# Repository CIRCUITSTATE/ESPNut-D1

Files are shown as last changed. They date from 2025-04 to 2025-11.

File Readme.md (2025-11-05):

# ESPNut-D1

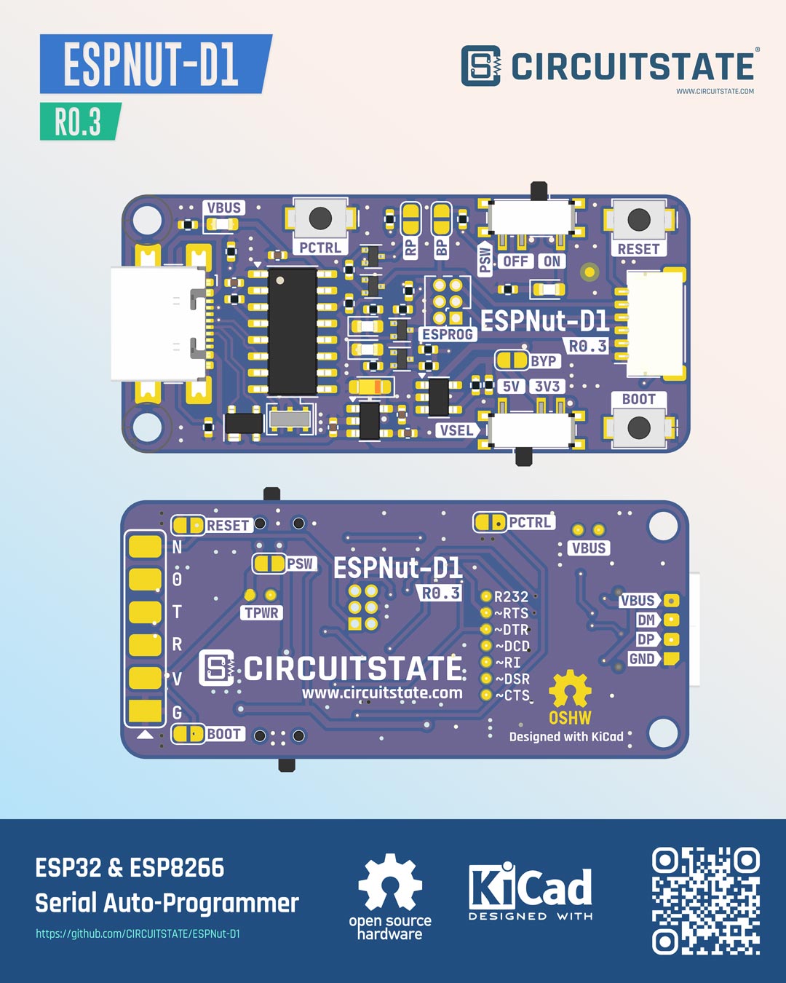
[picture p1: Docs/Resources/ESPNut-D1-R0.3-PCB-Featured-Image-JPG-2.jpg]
a title


[**ESPNut-D1**](https://github.com/CIRCUITSTATE/ESPNut-D1) (pronounced as **"ee yes peanut"**) is a single-channel USB-to-Serial converter and Auto-Programmer for the ESP32 & ESP8266 series microcontrollers from Espressif. While there exists many such programmers, ESPNut-D1 is a completely open-source hardware (OSHW) project designed in the **KiCad** open-source EDA tool. **D1** is the first design variant of this project. You can download the source files of this design, modify them and redistribute them as you wish.

ESPNut-D1 is based on the popular **CH340** series USB-to-Serial converter chip from *WCH*. The serial port of the chip connects to the target microcontroller through its own serial port. Thanks to the built-in serial bootloader of the ESP series microcontrollers, you can effortlessly program them at any time. The ESPNut-D1 makes this process a bit more convenient.

## Features

- CH340C/CH340G USB-to-Serial converter chip.
  - No external crystal required for the CH340C.
- USB-C connector with extra solderpads.
- Auto bootloader and reset circuit. Control both functions from the USB.
- Dedicated push-buttons for target reset and boot mode.
- 3.6~12V in, 3.3V out, 500 mA LDO.
- Slide switch for target power control.
- Target power control through load switch.
- SPDT slide switch for target voltage selection. Select between 3.3V and 5V.
- VBUS and target power indication LEDs.
- UART activity LEDs for both `TX` and `RX` lines.
- Dedicated push-button for power control of the target. Useful for boards without reset pin.
- 6-pin ESP-PROG 1.27 mm header.
- 6-pin JST-SH connector and solderpad for target ESP.
- 2x M2 mounting holes.

## Design

- **Parent Project:** ESPNut
- **Variant:** [ESPNut-D1](https://github.com/CIRCUITSTATE/ESPNut-D1)
- **Author:** Vishnu Mohanan (@vishnumaiea)
- **Latest Revision:** `R0.4`
- **Layer Count:** 2
- **Thickness:** 1.6 mm
- **Dimensions:** 44 x 20 mm
- **EDA Tool:** KiCad V9
- **License:** MIT

## Contributing

If you would like to contribute this project, you are welcome to post issues and feature requests on the **Issues** page. If you fork this project and created a new variant, you can let us know about it and get a unique identifier assigned for your project. The ID takes the following form.

```
Y<digit><letter><digit>
```

`Y` – Constant prefix.

`<digit>` – Digits from 0–9

`<letter>` – Characters from A–Z.

**Examples:**

```
Y1A1
Y1A2
Y2B1
Y3C4
```

The forked project should then be renamed to `ESPNut-D1-<ID>` form.

**Guidelines:**

- IDs are assigned upon request. You can create a new issue to request a new ID once a fork is created. Keep the issue title as `Request New ID` and include a link to your fork in the description.
- You can either request a new ID that you like and that is already not chosen, or allow us to choose an ID for you.
- You should rename the original source files with the `ESPNut-D1-<ID>` format.
- On the PCB, you can place the name of the project as `ESPNut-D1` and keep the ID as a standalone text on any visible layers.
- Once a unique ID is assigned to a forked project, the revision should be reset to `R0.1`. Do not keep the original revision of the project.

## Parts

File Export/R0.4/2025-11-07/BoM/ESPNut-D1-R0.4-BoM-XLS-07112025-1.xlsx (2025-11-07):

# | Reference | Value | Name | Footprint | Qty | DNP | MPN | MFR | Alt MPN
1 | C1,C8 | 47uF |  | Capacitor_SMD:C_0805_2012Metric | 2 |  | GRM21BR61A476ME15K | Murata | CC0805MKX5R6BB476
2 | C2,C3 | 0.1uF |  | Capacitor_SMD:C_0402_1005Metric | 2 |  | CC0402KRX5R6BB104 | Yageo
3 | C4,C7 | 4.7uF |  | Capacitor_SMD:C_0402_1005Metric | 2 |  | CC0402MRX5R5BB475 | Yageo
4 | C5 | 470pF |  | Capacitor_SMD:C_0402_1005Metric | 1 |  | 0402N471J500LT | Walsin
5 | C6 | 2.2uF |  | Capacitor_Tantalum_SMD:CP_EIA-2012-12_Kemet-R_Pad1.30x1.05mm_HandSolder | 1 |  | TAJR225M016RNJ | KYOCERA AVX
6 | D1 | VBUS_LED | VBUS_LED | LED_SMD:LED_0603_1608Metric | 1 |  | 19-21SURC/S530-A2/TR8 | Everlight
7 | D2 | BAS70K |  | Diode_SMD_AKL:D_SOD-523 | 1
8 | D3 | SP0503BAHT | TVS | Package_TO_SOT_SMD:SOT-143 | 1 |  | SP0503BAHTG | Littelfuse
9 | D4 | ESP_PWR | ESP_PWR | LED_SMD:LED_0603_1608Metric | 1 |  | 19-217UYOC/S3112/TR8 | Everlight
10 | D5 | RX_LED | RX_LED | LED_SMD:LED_0603_1608Metric | 1 |  | 19-213/BHC-ZL1M2RY/3T | Everlight
11 | D6 | TX_LED | TX_LED | LED_SMD:LED_0603_1608Metric | 1 |  | 19-217/R6C-AL1M2VY/3T | Everlight
12 | H1,H2,J2,J4,J5,JP1,JP2,JP3,JP4,JP5,JP6,JP7,JP8,JP9,TP1,TP2,TP3,TP4,TP5,TP6,TP7,TP8,TP9,TP10,TP11 | ACT-LED-V,BT_PUE,CTS,DCD,DSR,DTR,ESP_BOOT,ESP_CONN,ESP_PROG,ESP_PWR_1,ESP_RST,ESP_VDD_O,ESP_VDD_SW,Mounting Hole,POW_CTRL,R232,RI,RST_PUE,RTS,TRX-PUV,USB_PADS,VBUS,VBUS_LED_1,VDD_CTRL_BYP | ACT-LED-V,BT_PUE,CTS,DCD,DSR,DTR,ESP_BOOT,ESP_CONN,ESP_PROG,ESP_PWR_1,ESP_RST,ESP_VDD_O,Mounting Hole,POW_CTRL,R232,RI,RST_PUE,RTS,TRX-PUV,USB_PADS,VBUS,VBUS_LED_1,VDD_CTRL_BYP | CSE_Solder-Jumper:Solder-Jumper-1x2_P1.3mm_Open_Rounded_1.0x1.2mm,CSE_Solder-Jumper:Solder-Jumper_1x3_0402_Open,CSE_Solderpads:Solderpad_1x06_P2.54mm_Rounded_Rectangle,CSE_Solderpads:Solderpad_1x4_Rectangular_Rounded_1.2x1mm_P1.5mm,Connector_PinHeader_1.27mm:PinHeader_2x03_P1.27mm_Vertical,MountingHole:MountingHole_2.2mm_M2_DIN965,SparkFun-Connector:TestPoint-0.75mm | 25 |  | DNP | DNP
13 | J1 | USB_C_Receptacle_USB2.0 | USB-C | CSE_Connector_USB:USB_C_Receptacle_GCT_USB4110 | 1 |  | YTC-TC16-273A1 | Yi Yuan
14 | J3 | ESP_CONN | ESP_CONN | CSE_Connector_JST_SH:JST_SH_SM06B-SRSS-TB_1x06-1MP_P1.00mm_Horizontal | 1 |  | SM06B-SRSS-TB | JST
15 | Q1,Q3 | MMBT3904T-7-F |  | CSE_Package_TO_SOT_SMD:SOT-523 | 2 |  | MMBT3904T-7-F | Diodes Incorporated
16 | Q2 | 2SK3019-TP |  | CSE_Package_TO_SOT_SMD:SOT-523 | 1 |  | 2SK3019-TP | MCC
17 | R1,R12 | 220R |  | Resistor_SMD:R_0402_1005Metric | 2 |  | RC0402FR-7D220RL | Yageo
18 | R2,R6 | 5.1K |  | Resistor_SMD:R_0402_1005Metric | 2 |  | WR04X5101FTL | Walsin
19 | R3,R4,R5,R7,R8 | 10K |  | Resistor_SMD:R_0402_1005Metric | 5 |  | WR04X1002FTL | Walsin
20 | R9 | 10K |  | Resistor_SMD:R_0402_1005Metric | 1 |  | RC0402FR-0710KL | Yageo
21 | R10 | 220R |  | Resistor_SMD:R_0402_1005Metric | 1 | DNP | RC0402FR-7D220RL | Yageo
22 | R13,R14 | 1K |  | Resistor_SMD:R_0402_1005Metric | 2 |  | WR04X1001FTL | Walsin
23 | SW1,SW2,SW5 | ESP_BOOT,ESP_RST,POW_CTRL | ESP_BOOT,ESP_RST,POW_CTRL | CSE_Switch_SMD:CK_SW_SPST_UK-B0273-SP25Y | 3 |  | TS-1088R-02526 | XUNPU | BX-TS-26-3425TP
24 | SW3,SW4 | ESPV_SEL,ESP_VDD_SW | ESPV_SEL,ESP_VDD_SW | Button_Switch_SMD:SW_SPDT_PCM12 | 2 |  | PCM12SMTR | C&K
25 | U1 | CH340G | USB-Serial | Package_SO:SOIC-16_3.9x9.9mm_P1.27mm | 1 |  | CH340G | WCH | CH340C
26 | U2 | MIC5219-3.3YM5 | 3.3V LDO | Package_TO_SOT_SMD:SOT-23-5 | 1 |  | MIC5219-3.3YM5 | Microchip
27 | U3 | AP22804AW5 | Load Switch | Package_TO_SOT_SMD:SOT-23-5 | 1 |  | AP22804AW5-7 | Diodes Inc
28 | Y1 | 12MHz |  | Crystal:Resonator_SMD_Murata_CSTxExxV-3Pin_3.0x1.1mm | 1 |  | CSTNE12M0G52Z000R0 | Murata

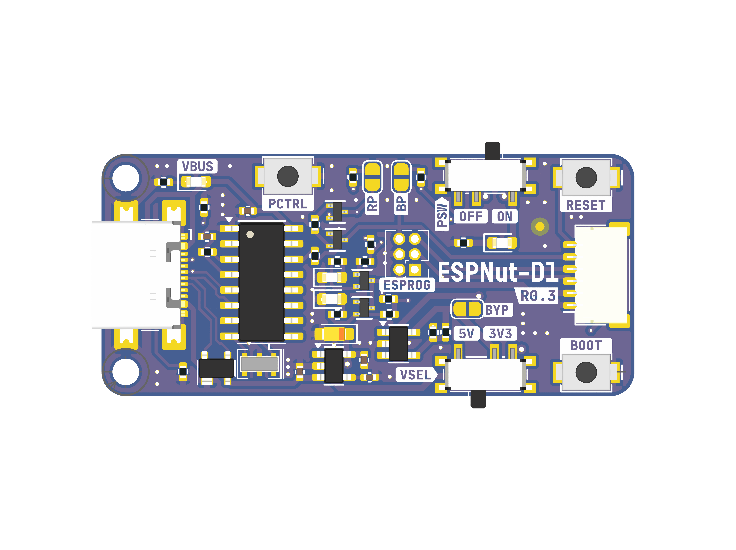
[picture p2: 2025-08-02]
Export/R0.3/2025-08-02/Renders/ESPNut-D1-R0.3-PCB-Parts-Front-02082025-1.png

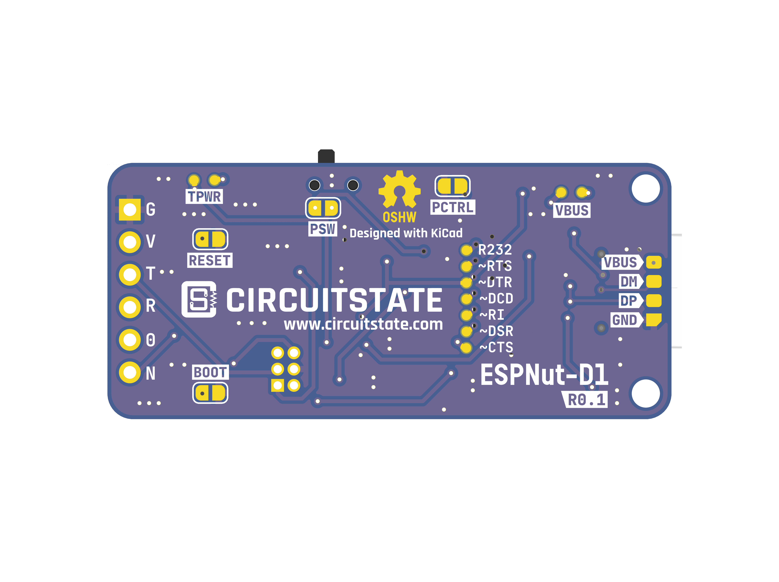
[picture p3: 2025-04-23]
Export/R0.1/2025-04-23/Renders/ESPNut-D1-R0.1-PCB-Parts-Back-23042025-1.png

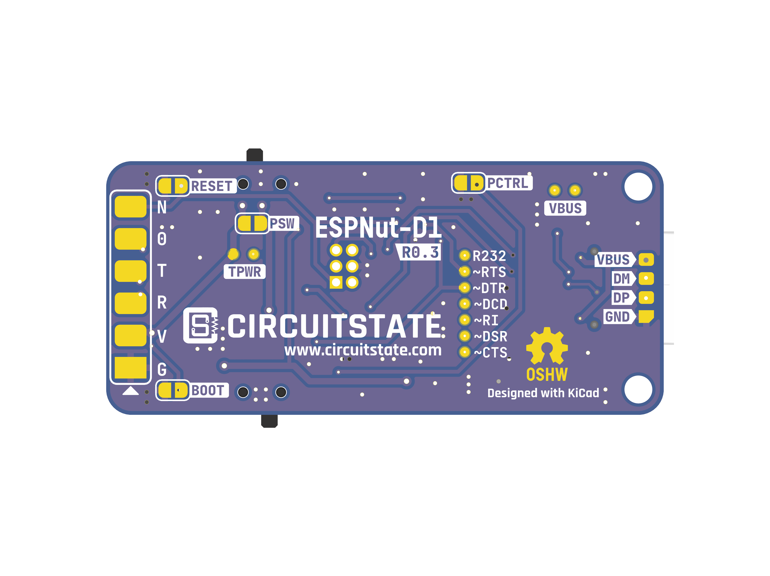
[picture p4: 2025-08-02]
Export/R0.3/2025-08-02/Renders/ESPNut-D1-R0.3-PCB-Parts-Back-02082025-1.png

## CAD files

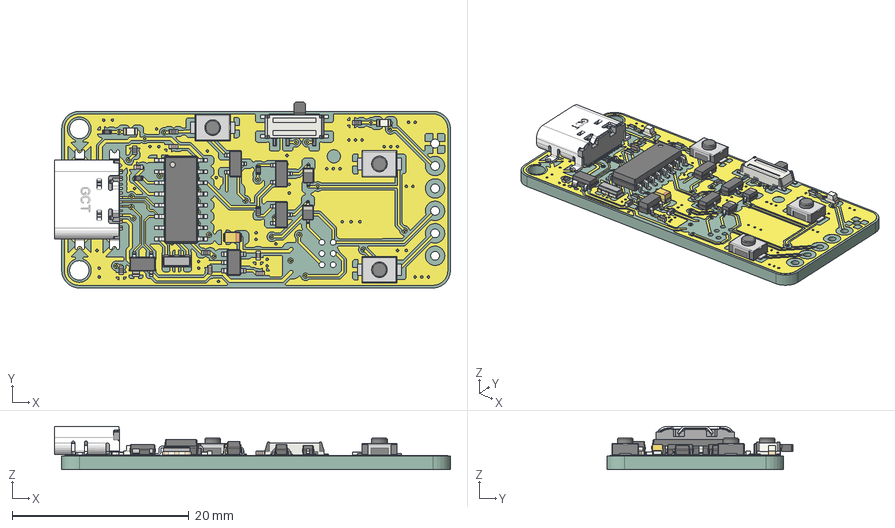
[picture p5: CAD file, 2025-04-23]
Export/R0.1/2025-04-23/3D/ESPNut-D1-R0.1-STEP-23042025-1.step
44.8 x 21.1 x 4.89 mm
R_0402_1005Metric x 9
D_SOD-323 x 2
LED_0603_1608Metric x 2
SOIC-16_3.9x9.9mm_P1.27mm
SW_SPDT_PCM12
C_0402_1005Metric x 5
Resonator_SMD_Murata_CSTxExxV-3Pin_3.0x1.1mm
SOT-23 x 3
SOT-143
CP_EIA-2012-12_Kemet-R
TS342-SPST-2P-3x4x2mm x 3
USB4110-GF-A_revB(1) MF
SOT-23-5
ESPNut-D1_copper
ESPNut-D1_via
ESPNut-D1_PCB

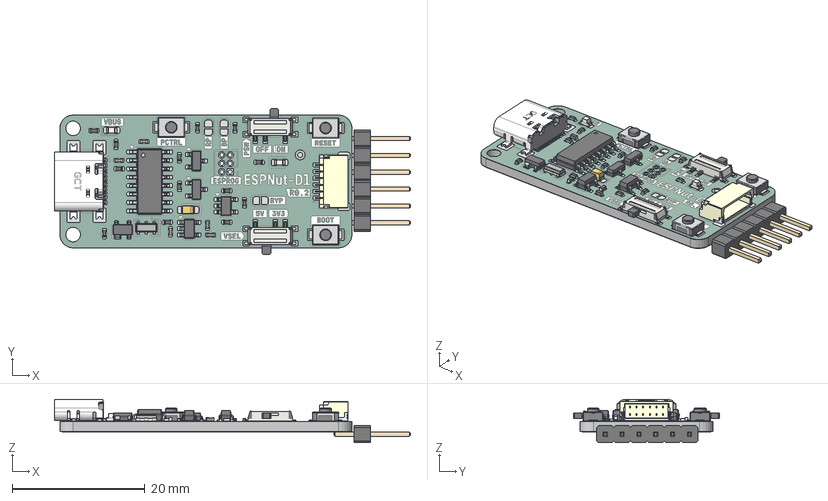
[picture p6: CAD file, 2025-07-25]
Export/R0.2/2025-07-25/3D/ESPNut-D1-R0.2-STEP-25072025-1.step
53.6 x 22.0 x 6.51 mm
SW_SPDT_PCM12 x 2
R_0402_1005Metric x 13
SOIC-16_3.9x9.9mm_P1.27mm
SOT-23-5 x 2
C_0402_1005Metric x 5
Resonator_SMD_Murata_CSTxExxV-3Pin_3.0x1.1mm
SOT-23 x 2
SOT-143
CP_EIA-2012-12_Kemet-R
TS342-SPST-2P-3x4x2mm x 3
USB4110-GF-A_revB(1) MF
LED_0603_1608Metric x 2
SM06B-SRSS-TB-LF-SN
PinHeader_1x06_P2.54mm_Vertical
ESPNut-D1_copper
ESPNut-D1_pad
ESPNut-D1_via
ESPNut-D1_silkscreen
ESPNut-D1_soldermask
ESPNut-D1_PCB

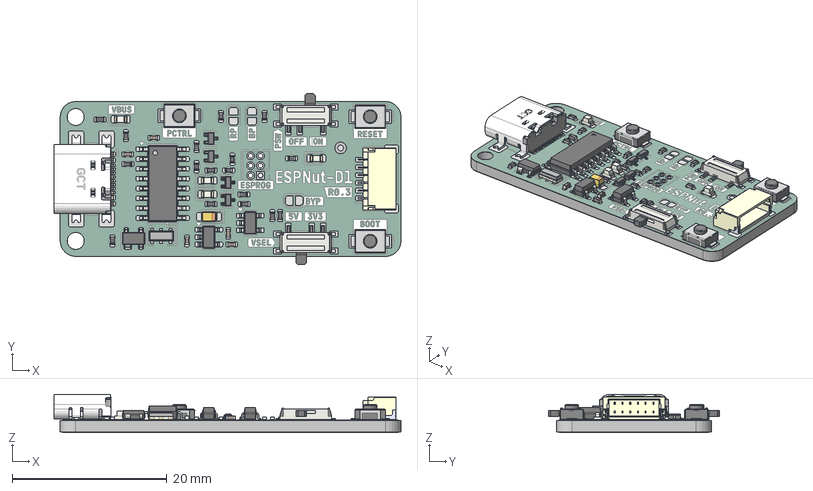
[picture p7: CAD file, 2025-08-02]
Export/R0.3/2025-08-02/3D/ESPNut-D1-R0.3-STEP-02082025-1.step
44.8 x 22.0 x 4.93 mm
SW_SPDT_PCM12 x 2
LF x 4
CPD x 4
R_0402_1005Metric x 17
SOIC-16_3.9x9.9mm_P1.27mm
SOT-23-5 x 2
C_0402_1005Metric x 5
Resonator_SMD_Murata_CSTxExxV-3Pin_3.0x1.1mm
LED_0603_1608Metric x 4
SOT-143
CP_EIA-2012-12_Kemet-R
TS342-SPST-2P-3x4x2mm x 3
USB4110-GF-A_revB(1) MF
SM06B-SRSS-TB-LF-SN
ESPNut-D1_copper
ESPNut-D1_pad
ESPNut-D1_via
ESPNut-D1_silkscreen
ESPNut-D1_soldermask
ESPNut-D1_PCB

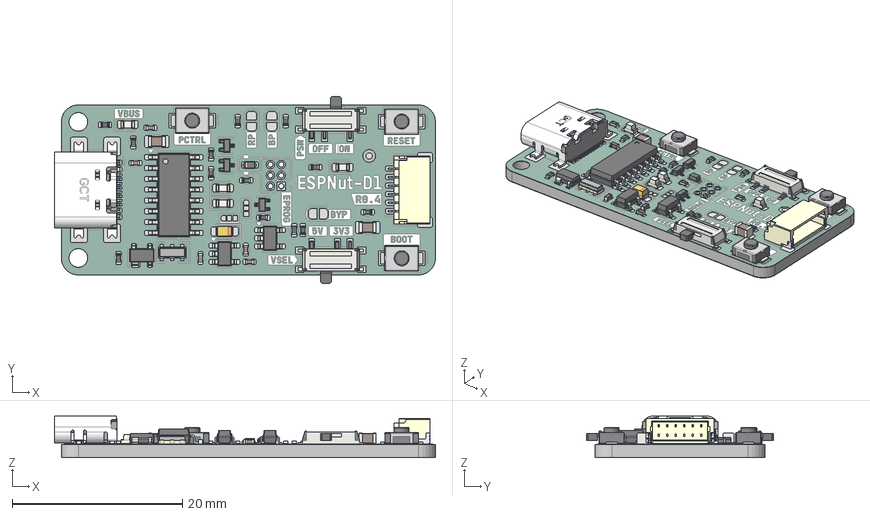
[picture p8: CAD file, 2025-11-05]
Export/R0.4/2025-11-05/3D/ESPNut-D1-R0.4-STEP-05112025-1.step
44.8 x 22.0 x 4.93 mm
SW_SPDT_PCM12 x 2
R_0402_1005Metric x 13
SOIC-16_3.9x9.9mm_P1.27mm
SOT-23-5 x 2
C_0805_2012Metric x 2
C_0402_1005Metric x 5
Resonator_SMD_Murata_CSTxExxV-3Pin_3.0x1.1mm
LF x 3
CPD x 3
LED_0603_1608Metric x 4
SOT-143
CP_EIA-2012-12_Kemet-R
TS342-SPST-2P-3x4x2mm x 3
USB4110-GF-A_revB(1) MF
SM06B-SRSS-TB-LF-SN
D_SOD-523
ESPNut-D1_copper
ESPNut-D1_pad
ESPNut-D1_via
ESPNut-D1_silkscreen x 2
ESPNut-D1_soldermask x 2
ESPNut-D1_PCB

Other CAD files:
Export/R0.3/2025-10-25/3D/ESPNut-D1-R0.3-STEP-25102025-1.step
Export/R0.4/2025-11-07/3D/ESPNut-D1-R0.4-STEP-07112025-1.step

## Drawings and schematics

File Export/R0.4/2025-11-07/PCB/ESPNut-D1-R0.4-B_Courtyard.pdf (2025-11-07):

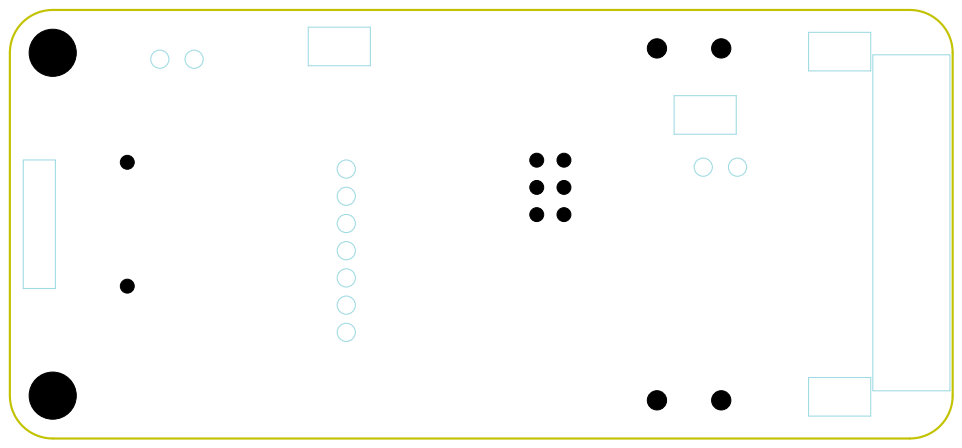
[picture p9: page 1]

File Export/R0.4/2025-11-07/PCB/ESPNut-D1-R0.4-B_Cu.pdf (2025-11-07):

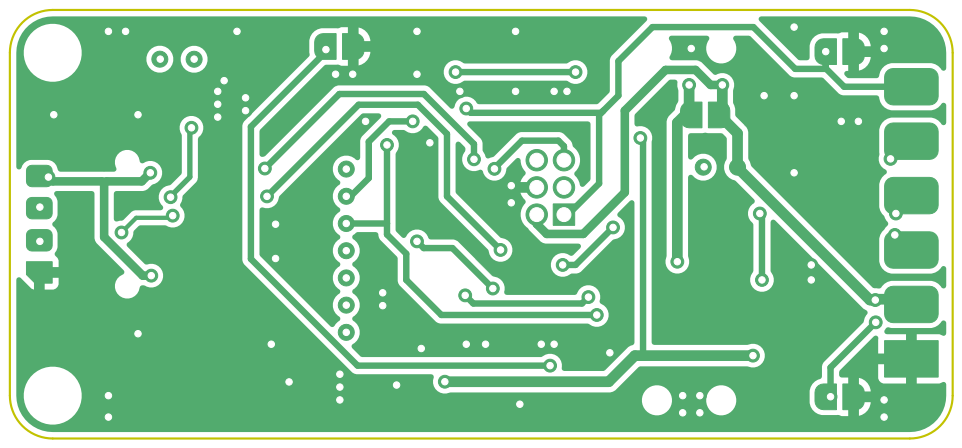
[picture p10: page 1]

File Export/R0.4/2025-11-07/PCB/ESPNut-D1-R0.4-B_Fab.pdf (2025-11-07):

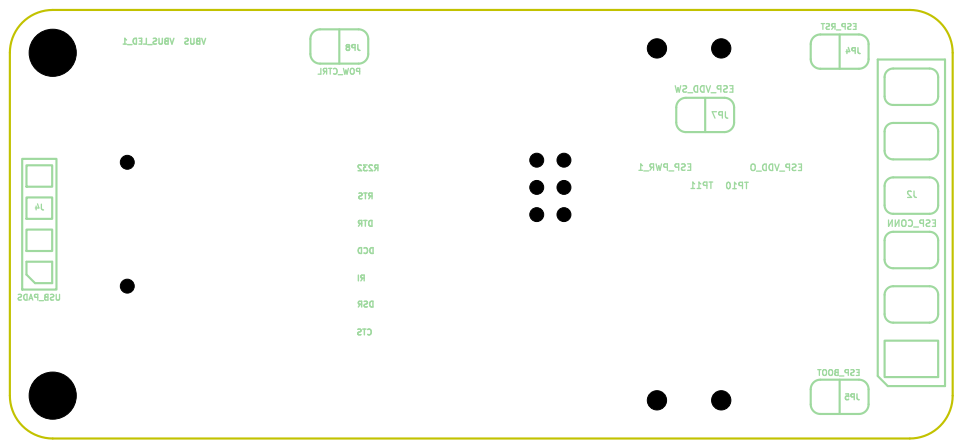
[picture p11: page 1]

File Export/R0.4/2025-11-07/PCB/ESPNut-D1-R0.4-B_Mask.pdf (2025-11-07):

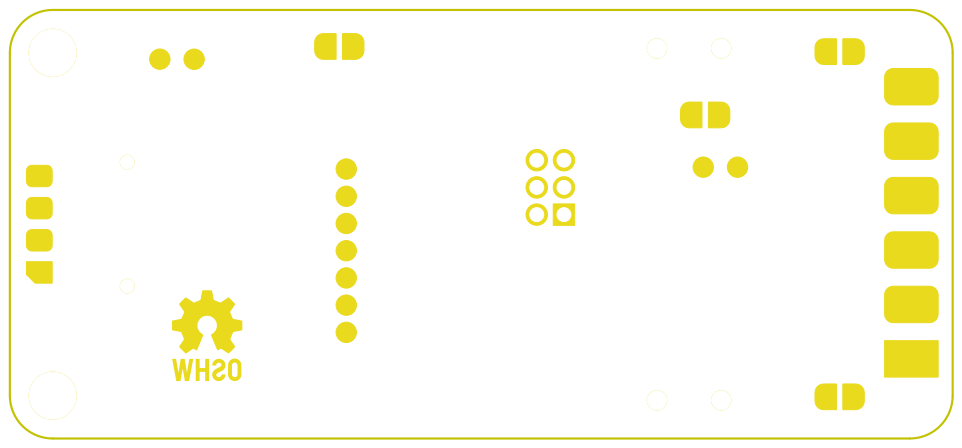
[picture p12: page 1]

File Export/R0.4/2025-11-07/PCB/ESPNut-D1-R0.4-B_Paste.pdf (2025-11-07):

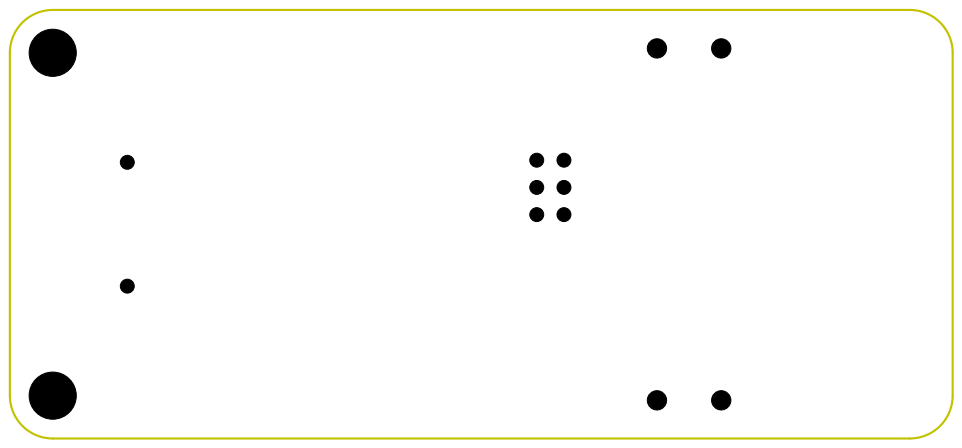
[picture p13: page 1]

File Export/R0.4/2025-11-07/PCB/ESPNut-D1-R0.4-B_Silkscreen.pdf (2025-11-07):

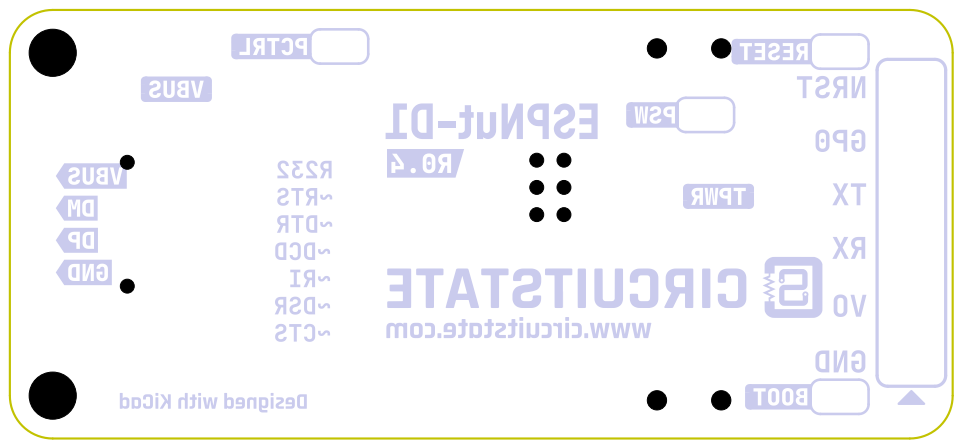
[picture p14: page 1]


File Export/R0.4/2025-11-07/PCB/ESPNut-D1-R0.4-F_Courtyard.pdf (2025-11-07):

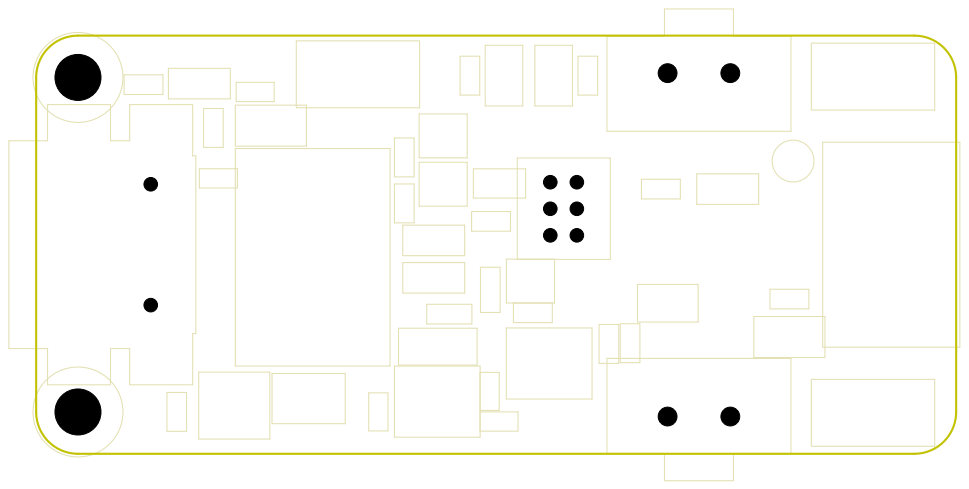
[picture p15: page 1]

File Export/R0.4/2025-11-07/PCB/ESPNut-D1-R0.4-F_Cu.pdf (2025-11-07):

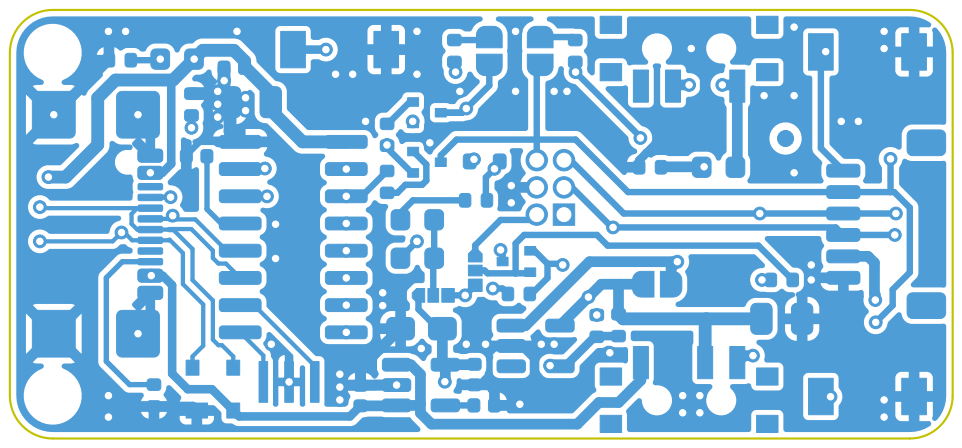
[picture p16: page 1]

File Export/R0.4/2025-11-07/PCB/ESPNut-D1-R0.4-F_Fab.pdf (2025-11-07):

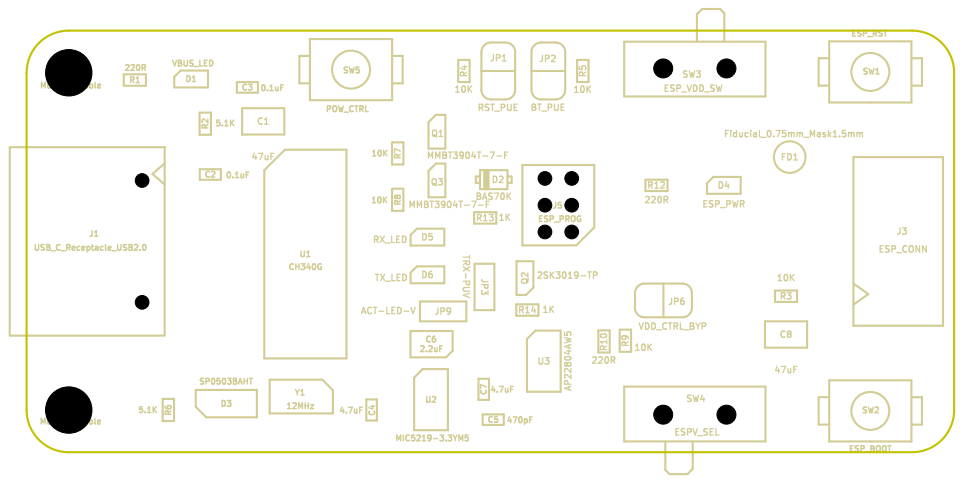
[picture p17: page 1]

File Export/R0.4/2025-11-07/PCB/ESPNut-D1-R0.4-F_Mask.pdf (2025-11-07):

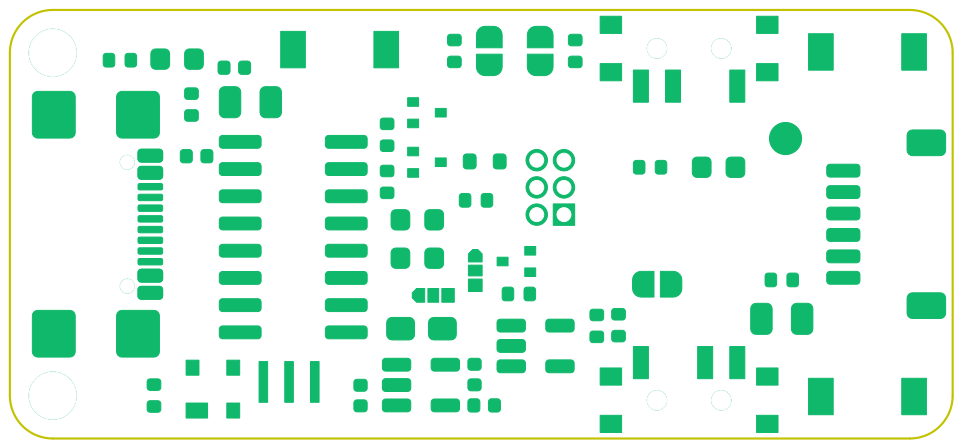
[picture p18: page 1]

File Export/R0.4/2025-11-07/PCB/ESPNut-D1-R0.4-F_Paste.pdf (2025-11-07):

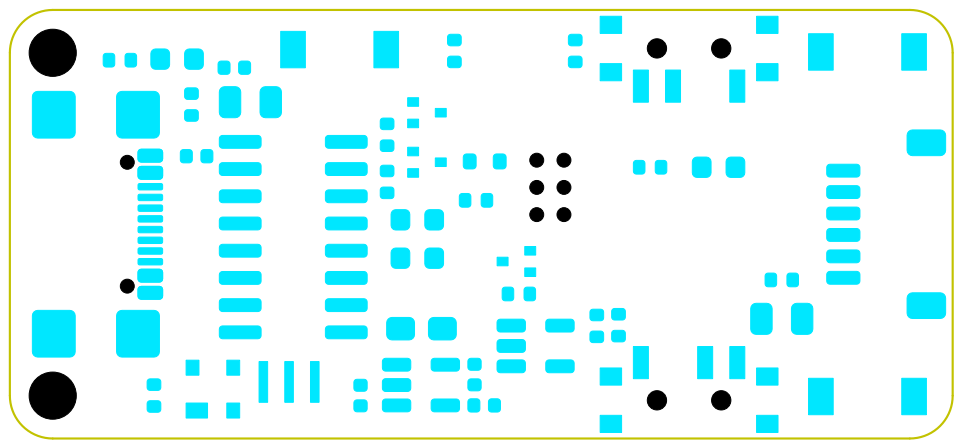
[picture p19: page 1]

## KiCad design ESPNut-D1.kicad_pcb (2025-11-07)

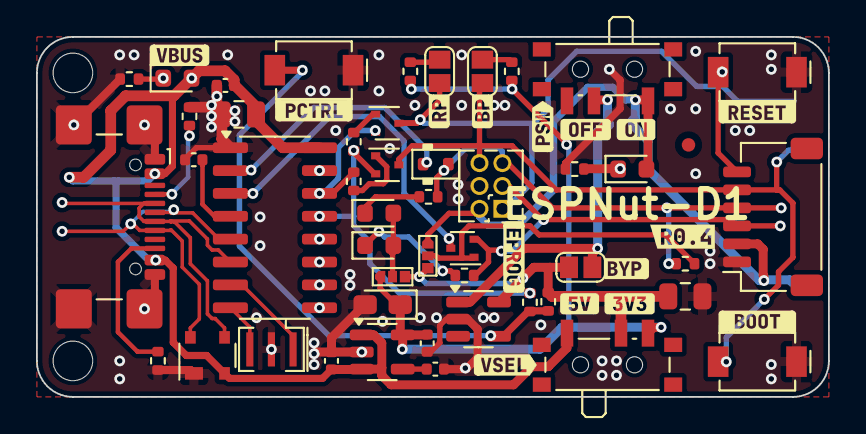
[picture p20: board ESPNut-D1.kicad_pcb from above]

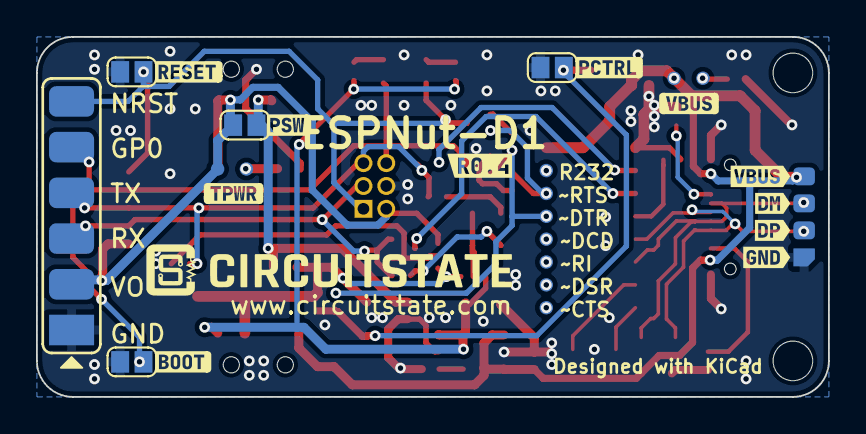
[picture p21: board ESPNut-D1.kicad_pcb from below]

Board: 2 copper layers, 44.0 x 20.0 mm, 93 parts (28 on the bottom side), 38 nets.

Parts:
C1, C8: 47uF; C_0805_2012Metric
C2, C3: 0.1uF; C_0402_1005Metric
C4, C7: 4.7uF; C_0402_1005Metric
C5: 470pF; C_0402_1005Metric
C6: 2.2uF; CP_EIA-2012-12_Kemet-R_Pad1.30x1.05mm_HandSolder
D1: VBUS_LED; LED_0603_1608Metric
D2: BAS70K; D_SOD-523
D3: SP0503BAHT; SOT-143
D4: ESP_PWR; LED_0603_1608Metric
D5: RX_LED; LED_0603_1608Metric
D6: TX_LED; LED_0603_1608Metric
FD1: Fiducial_0.75mm_Mask1.5mm
H1, H2: Mounting Hole; MountingHole_2.2mm_M2_DIN965
J1: USB_C_Receptacle_USB2.0; USB_C_Receptacle_GCT_USB4110
J2: ESP_CONN; Solderpad_1x06_P2.54mm_Rounded_Rectangle
J3: ESP_CONN; JST_SH_SM06B-SRSS-TB_1x06-1MP_P1.00mm_Horizontal
J4: USB_PADS; Solderpad_1x4_Rectangular_Rounded_1.2x1mm_P1.5mm
J5: ESP_PROG; PinHeader_2x03_P1.27mm_Vertical
JP1: RST_PUE; Solder-Jumper-1x2_P1.3mm_Open_Rounded_1.0x1.2mm
JP2: BT_PUE; Solder-Jumper-1x2_P1.3mm_Open_Rounded_1.0x1.2mm
JP3: TRX-PUV; Solder-Jumper_1x3_0402_Open
JP4: ESP_RST; Solder-Jumper-1x2_P1.3mm_Open_Rounded_1.0x1.2mm
JP5: ESP_BOOT; Solder-Jumper-1x2_P1.3mm_Open_Rounded_1.0x1.2mm
JP6: VDD_CTRL_BYP; Solder-Jumper-1x2_P1.3mm_Open_Rounded_1.0x1.2mm
JP7: ESP_VDD_SW; Solder-Jumper-1x2_P1.3mm_Open_Rounded_1.0x1.2mm
JP8: POW_CTRL; Solder-Jumper-1x2_P1.3mm_Open_Rounded_1.0x1.2mm
JP9: ACT-LED-V; Solder-Jumper_1x3_0402_Open
Q1, Q3: MMBT3904T-7-F; SOT-523
Q2: 2SK3019-TP; SOT-523
R1, R10, R12: 220R; R_0402_1005Metric
R2, R6: 5.1K; R_0402_1005Metric
R3, R4, R5, R7, R8, R9: 10K; R_0402_1005Metric
R13, R14: 1K; R_0402_1005Metric
SW1: ESP_RST; CK_SW_SPST_UK-B0273-SP25Y
SW2: ESP_BOOT; CK_SW_SPST_UK-B0273-SP25Y
SW3: ESP_VDD_SW; SW_SPDT_PCM12
SW4: ESPV_SEL; SW_SPDT_PCM12
SW5: POW_CTRL; CK_SW_SPST_UK-B0273-SP25Y
TP1: VBUS; TestPoint-0.75mm
TP2: VBUS_LED_1; TestPoint-0.75mm
TP3: R232; TestPoint-0.75mm
TP4: CTS; TestPoint-0.75mm
TP5: DSR; TestPoint-0.75mm
TP6: RI; TestPoint-0.75mm
TP7: DCD; TestPoint-0.75mm
TP8: DTR; TestPoint-0.75mm
TP9: RTS; TestPoint-0.75mm
TP10: ESP_VDD_O; TestPoint-0.75mm
TP11: ESP_PWR_1; TestPoint-0.75mm
U1: CH340G; SOIC-16_3.9x9.9mm_P1.27mm
U2: MIC5219-3.3YM5; SOT-23-5
U3: AP22804AW5; SOT-23-5
Y1: 12MHz; Resonator_SMD_Murata_CSTxExxV-3Pin_3.0x1.1mm
kibuzzard-67F0B0FE: G***; kibuzzard-67F0B0FE
kibuzzard-67F0B154: G***; kibuzzard-67F0B154
kibuzzard-67F0B222, kibuzzard-67F0B222#2: G***; kibuzzard-67F0B222
kibuzzard-67F0C2BD: G***; kibuzzard-67F0C2BD
kibuzzard-67F0C2E8: G***; kibuzzard-67F0C2E8
kibuzzard-67F0C30C: G***; kibuzzard-67F0C30C
kibuzzard-67F0C300: G***; kibuzzard-67F0C300
kibuzzard-67F0C318: G***; kibuzzard-67F0C318
kibuzzard-690A4E8D: G***; kibuzzard-690A4E8D
kibuzzard-690A4E32: G***; kibuzzard-690A4E32
kibuzzard-690A4E84: G***; kibuzzard-690A4E84
kibuzzard-68837A0C: G***; kibuzzard-68837A0C
kibuzzard-68837ACD: G***; kibuzzard-68837ACD
kibuzzard-68837FCA: G***; kibuzzard-68837FCA
kibuzzard-688268B9: G***; kibuzzard-688268B9
kibuzzard-688269BA: G***; kibuzzard-688269BA
kibuzzard-688269D8: G***; kibuzzard-688269D8
kibuzzard-688272B9: G***; kibuzzard-688272B9
kibuzzard-688272CF: G***; kibuzzard-688272CF
kibuzzard-688273BB: G***; kibuzzard-688273BB
kibuzzard-6882689F: G***; kibuzzard-6882689F
kibuzzard-68826928: G***; kibuzzard-68826928
kibuzzard-68826931: G***; kibuzzard-68826931
kibuzzard-68827414: G***; kibuzzard-68827414
kibuzzard-68827490: G***; kibuzzard-68827490

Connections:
+3V3: C6.1, C7.1, JP9.1 (A), R4.1, R5.1, SW4.3 (C), U2.5 (OUT)
/CH_RX: J2.3, J3.3, J5.3, Q2.2 (S), R14.2
/CH_TX: D2.2 (A), J2.4, J3.4, J5.5, R3.2, R13.2
/DTR: Q3.2 (E), R7.2, R10.2, TP8.1, U1.13 (~DTR)
/ESP_IO0: J2.5, J3.5, J5.6, JP2.1 (A), JP5.2 (B), Q3.3 (C), SW2.2
/ESP_NRST: J2.6, J3.6, J5.1, JP1.1 (A), JP4.2 (B), Q1.3 (C), SW1.2
/ESP_VDD_I: C8.1, JP3.3 (B), JP6.2 (B), JP9.3 (B), R9.2, SW4.2 (B), U3.5 (IN)
/ESP_VDD_O: D4.2 (A), J2.2, J3.2, J5.2, JP3.1 (A), JP7.1 (A), SW3.1 (A), TP10.1
/RTS: Q1.2 (E), R8.2, TP9.1, U1.14 (~RTS)
/USB_D+: D3.4 (K), J1.A6 (D+), J1.B6 (D+), J4.2, U1.5 (UD+)
/USB_D-: D3.3 (K), J1.A7 (D-), J1.B7 (D-), J4.3, U1.6 (UD-)
/V3: C2.1, U1.4 (V3)
GND: C1.1, C2.2, C3.2, C4.2, C5.2, C6.2, C7.2, C8.2, D3.1 (A), J1.A1 (GND), J1.A12 (GND), J1.B1 (GND), J1.B12 (GND), J1.S1 (SHIELD), J2.1, J3.1, J4.1, J5.4, JP4.1 (A), JP5.1 (A), JP8.1 (A), R1.1, R2.2, R6.2, R12.1, SW1.1, SW2.1, SW5.1, U1.1 (GND), U2.2 (GND), U3.2 (GND), Y1.2
unnamed: D1.1 (K), R1.2, TP2.1
unnamed: D2.1 (K), U1.2 (TXD)
unnamed: D4.1 (K), R12.2, TP11.1
unnamed: D5.2 (A), D6.2 (A), JP9.2 (C)
unnamed: D5.1 (K), R13.1
unnamed: D6.1 (K), R14.1
unnamed: J1.A5 (CC1), R2.1
unnamed: J1.B5 (CC2), R6.1
unnamed: JP1.2 (B), R4.2
unnamed: JP2.2 (B), R5.2
unnamed: JP3.2 (C), Q2.1 (G), R3.1
unnamed: JP6.1 (A), JP7.2 (B), SW3.2 (B), U3.1 (OUT)
unnamed: JP8.2 (B), R9.1, R10.1, SW5.2, U3.4 (EN)
unnamed: Q1.1 (B), R7.1
unnamed: Q2.3 (D), U1.3 (RXD)
unnamed: Q3.1 (B), R8.1
unnamed: TP3.1, U1.15 (R232)
unnamed: U1.7 (XI), Y1.1
unnamed: U1.8 (XO), Y1.3
unnamed: TP4.1, U1.9 (~CTS)
unnamed: TP7.1, U1.12 (~DCD)
unnamed: TP5.1, U1.10 (~DSR)
unnamed: TP6.1, U1.11 (~RI)
unnamed: C5.1, U2.4 (BP)
VBUS: C1.2, C3.1, C4.1, D1.2 (A), D3.2 (K), J1.A4 (VBUS), J1.A9 (VBUS), J1.B4 (VBUS), J1.B9 (VBUS), J4.4, SW4.1 (A), TP1.1, U1.16 (VCC), U2.1 (IN), U2.3 (EN)

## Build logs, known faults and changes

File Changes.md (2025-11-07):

# Changes

#
### **+05:30 08:27:13 PM 07-11-2025, Friday**

  - Changed all via sizes to `0.6/0.3 mm` to comply with Lion Circuits.
  - Generated new manufacturing files. 

#
### **+05:30 10:31:51 PM 05-11-2025, Wednesday**

  - Schematic
    - Removed the PNP transistors from the UART activity LED circuit.
      - The SparkFun Serial Basic directly connects the LEDs to the TX and RX lines via `1K` resistors.
      - We will do the same.
      - But the voltage supplied to the LEDs can be set using a jumper `ACT-LED-V`.
    - Added jumper `TRX-PUV` to the CH340 communication lines.
      - This jumper selects between `ESP_VDD_I` and `ESP_VDD_O` for the pull-ups.
    - ERC passes.
  - PCB
    - Imported all changes to the PCB.
    - Placement and routing completed.
    - DRC passes.
  - This will be a test version and aesthetics don't matter now.
  - Generated manufacturing files.
  - New Revision 🆕 `R0.4`.

#
### **+05:30 07:43:05 PM 04-11-2025, Tuesday**

  - Schematic
    - Added `47 uF` 0805 capacitors to the VBUS line, near the CH340 and `ESP_VDD_I`.
      - This was required because it was observed that the CH340 will reset when a significant load is connected to the `VBUS` line.
      - Adding two 22 uF capacitors proved to solve the issue.
      - But we are going to use 47 uF capacitors for better stability.
  - PCB
    - Imported all changes to the PCB.
    - DRC passes.
  - No version changes.

#
### **+05:30 03:11:22 PM 02-08-2025, Saturday**

  - Updated BoM.
    - Fixed UART activity LEDs MPNs.
  - Generated new manufacturing files.

#
### **+05:30 11:52:12 AM 02-08-2025, Saturday**

  - Schematic
    - Added DPDT `UART_SWAP` switch to swap the `TX` and `RX` lines.
      - But this is DNPed because the switch consumes too much space.
    - Added UART activity LEDs on both `TX` and `RX` lines.
    - Changed all existing transistor footprints to `SOT-523`.
    - Excluded `AP22804AW5`'s `FLG` resistor from the board.
    - Updated the BoM.
    - Reset the annotations.
  - PCB
    - Imported all changes to the PCB.
    - Updated placements.
    - Routing completed.
    - Updated Fab layers.
    - DRC passes.
  - Generated manufacturing files.

#
### **+05:30 09:10:16 PM 30-07-2025, Wednesday**

  - Schematic
    - Added `DIFF` class for differential pairs.
    - Added `1K` series resistors to both the `TX` and `RX` lines.
      - This will limit the current and reverse voltage to the target.
      - Previously we only had a single `220R` resistor on the `RX` line of the `CH340`.
      - A value of `1K` does not affect performance.
  - New Revision 🆕 `R0.3`.

#
### **+05:30 07:15:29 PM 25-07-2025, Friday**

  - Updated KiExport configuration to `v1.7`.
  - Generated manufacturing files.

#
### **+05:30 06:41:27 PM 25-07-2025, Friday**

  - Schematic
    - Updated BoM.
    - Reset the annotations.
  - PCB
    - Imported all changes to the PCB.
    - Routing completed.
    - DRC passes.
    - Updated Fab layers.

#
### **+05:30 06:47:35 PM 24-07-2025, Thursday**

  - Schematic
    - Deleted the Mosfet based power control circuit.
      - Replaced it with `AP22804AW5` based circuit.
      - Not because it is not working, but because a proper load switch is more reliable.
    - Added 6-pin `SM06B-SRSS-TB` JST-SH connector for target ESP.
      - The THT pin-headers will be changes to SMD one and placed on the back side.
    - Added `PCM12SMTR` SPDT switch for ESP voltage selection.
      - Removed the 3-pin solder jumper.
  - PCB
    - Imported all changes to the PCB.
    - Deleted all existing tracks and vias.
    - Rearranged the components.
    - Updated label styles and placements.
    - There is now more alignment and symmetry.
    - Routing pending.
  - New Revision 🆕 `R0.2`.

#
### **+05:30 11:49:21 PM 23-07-2025, Wednesday**

  - Schematic
    - Removed the `RB751V40` diodes.
      - These are not used in the official ESP-Prog design and everything works fine without them.
    - DNPed the resistor between `DTR` and the power-control Mosfet.
      - Since this technique doesn't work reliably, we will not use it.
    - Added `10K` pull-up resistors on the `RESET` and `BOOT` lines with solder jumpers.

#
### **+05:30 09:54:52 PM 23-04-2025, Wednesday**

  - Added fiducial to the front side.
  - Generated new manufacturing files.
  - Updated Readme.

#
### **+05:30 07:14:23 PM 12-04-2025, Saturday**

  - Generated new manufacturing files using KiExport.
  - Updated Readme.

#
### **+05:30 09:41:05 AM 09-04-2025, Wednesday**

  - Added KiExport configuration and script.
  - Added dimension drawings.
  - Added board characteristics and stackup table.
  - Added `OSHW` logo.
  - Generated manufacturing files.

#
### **+05:30 05:59:31 PM 08-04-2025, Tuesday**

  - Updated BoM.
    - Assigned all MPNs.
    - Changed the 10 uF, 0402 capacitor to 4.7 uF, 0402.
  - Imported all changes to the PCB.

#
### **+05:30 05:13:40 PM 08-04-2025, Tuesday**

  - Routing completed.
  - Added GND zones.
  - DRC passes.
  - Added more silkscreen labels.
  - Added CIRCUITSTATE logo on the back silkscreen.
  - Updated Fab layers.

#
### **+05:30 11:07:23 AM 05-04-2025, Saturday**

  - Added breakout pads for the LEDs.
  - Changed USB-C connector footprint to SMD one.
  - Added PCB outline.
  - Placed all components.
  - Added silkscreen labels and logos.
  - Routing pending.

#
### **+05:30 10:32:36 PM 04-04-2025, Friday**

  - Added `M2` mounting holes.

#
### **+05:30 09:47:14 PM 04-04-2025, Friday**

  - Updated project version to KiCad V9.
  - Updated text colors.

#
### **+05:30 11:55:36 PM 26-08-2024, Monday**

  - Added net classes and highlights.
  - Added Changes and Readme.
  - Added `.gitignore`.
  - New Revision 🆕 `R0.1`.

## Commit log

2024-08-26 R0.1 Initial Commit
    * Added net classes and highlights.
    * Added Changes and Readme.
    * Added `.gitignore`.
    * New Revision `R0.1`.
    [ESPNut-D1.kicad_pcb, ESPNut-D1.kicad_sch]
2025-04-04 Updated project version to KiCad V9
    - Updated text colors.
    [ESPNut-D1.kicad_pcb, ESPNut-D1.kicad_sch]
2025-04-05 Placement completed
    - Added breakout pads for the LEDs.
    - Changed USB-C connector footprint to SMD one.
    - Added PCB outline.
    - Placed all components.
    - Added silkscreen labels and logos.
    - Routing pending.
    [ESPNut-D1.kicad_pcb, ESPNut-D1.kicad_sch]
2025-04-08 Routing completed
    - Added GND zones.
    - DRC passes.
    - Added more silkscreen labels.
    - Added CIRCUITSTATE logo on the back silkscreen.
    - Updated Fab layers.
    [ESPNut-D1.kicad_pcb, ESPNut-D1.kicad_sch]
2025-04-08 Updated BoM
    - Updated BoM.
    - Assigned all MPNs.
    - Changed the 10 uF, 0402 capacitor to 4.7 uF, 0402.
    - Imported all changes to the PCB.
    [ESPNut-D1.kicad_pcb, ESPNut-D1.kicad_sch]
2025-04-09 Generated manufacturing files
    - Added KiExport configuration and script.
    - Added dimension drawings.
    - Added board characteristics and stackup table.
    - Added `OSHW` logo.
    [ESPNut-D1-R0.1-BoM-CSV-09042025-1.csv, ESPNut-D1-R0.1-BoM-XLS-09042025-1.xlsx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]
2025-04-12 Generated new manufacturing files
    - Updated Readme.
    [ESPNut-D1-R0.1-BoM-CSV-12042025-1.csv, ESPNut-D1-R0.1-BoM-XLS-09042025-1.xlsx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]
2025-04-23 Added fiducial
    - Added fiducial to the front side.
    - Generated new manufacturing files.
    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
    [ESPNut-D1-R0.1-BoM-CSV-09042025-1.csv, ESPNut-D1-R0.1-BoM-CSV-12042025-1.csv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]
2025-07-24 New Revision `R0.2`
    - Schematic
    - Deleted the Mosfet based power control circuit.
    - Replaced it with `AP22804AW5` based circuit.
    - Not because it is not working, but because a proper load switch is more reliable.
    - Added 6-pin `SM06B-SRSS-TB` JST-SH connector for target ESP.
    - The THT pin-headers will be changes to SMD one and placed on the back side.
    - Added `PCM12SMTR` SPDT switch for ESP voltage selection.
    - Removed the 3-pin solder jumper.
    - PCB
    - Deleted all existing tracks and vias.
    - Rearranged the components.
    - Updated label styles and placements.
    - There is now more alignment and symmetry.
    - New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
    [ESPNut-D1.kicad_pcb, ESPNut-D1.kicad_sch]
2025-07-25 Routing completed
    - Reset the annotations.
    - Routing completed.
    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
    [ESPNut-D1.kicad_pcb, ESPNut-D1.kicad_sch]
2025-07-25 Generated manufacturing files
    - Updated KiExport configuration to `v1.7`.
    - Generated manufacturing files.
    [ESPNut-D1-R0.2-BoM-CSV-25072025-1.csv, ESPNut-D1-R0.2-BoM-XLS-25072025-1.xlsx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]
2025-08-02 New Revision `R0.3` - Schematic - Added DPDT `UART_SWAP` switch to swap the `TX` and `RX` lines. - But this is DNPed because the switch consumes too much space. - Added UART activity LEDs on both `TX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
    [ESPNut-D1-R0.3-BoM-CSV-02082025-1.csv, ESPNut-D1-R0.3-BoM-XLS-02082025-1.xlsx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]
2025-08-02 Updated BoM
    - Fixed UART activity LEDs MPNs.
    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
    [ESPNut-D1-R0.3-BoM-CSV-02082025-1.csv, ESPNut-D1-R0.3-BoM-XLS-02082025-1.xlsx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]
2025-11-04 Added `47 uF` 0805 capacitors
    - Added `47 uF` 0805 capacitors to the VBUS line, near the CH340 and `ESP_VDD_I`.
    - This was required because it was observed that the CH340 will reset when a significant load is connected to the `VBUS` line.
    - Adding two 22 uF capacitors proved to solve the issue.
    - But we are going to use 47 uF capacitors for better stability.
    - No version changes.
    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
    [ESPNut-D1-R0.3-BoM-CSV-25102025-1.csv, ESPNut-D1-R0.3-BoM-XLS-25102025-1.xlsx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]
2025-11-05 New Revision 🆕 `R0.4`
    - Removed the PNP transistors from the UART activity LED circuit.
    - The SparkFun Serial Basic directly connects the LEDs to the TX and RX lines via `1K` resistors.
    - We will do the same.
    - But the voltage supplied to the LEDs can be set using a jumper `ACT-LED-V`.
    - Added jumper `TRX-PUV` to the CH340 communication lines.
    - This jumper selects between `ESP_VDD_I` and `ESP_VDD_O` for the pull-ups.
    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
    [ESPNut-D1-R0.4-BoM-CSV-05112025-1.csv, ESPNut-D1-R0.4-BoM-XLS-05112025-1.xlsx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]
2025-11-07 Changed all via sizes to `0.6/0.3 mm`
    - Changed all via sizes to `0.6/0.3 mm` to comply with Lion Circuits.
    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
    [ESPNut-D1-R0.4-BoM-CSV-07112025-1.csv, ESPNut-D1-R0.4-BoM-XLS-07112025-1.xlsx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]

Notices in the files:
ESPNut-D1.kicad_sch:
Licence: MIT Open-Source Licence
